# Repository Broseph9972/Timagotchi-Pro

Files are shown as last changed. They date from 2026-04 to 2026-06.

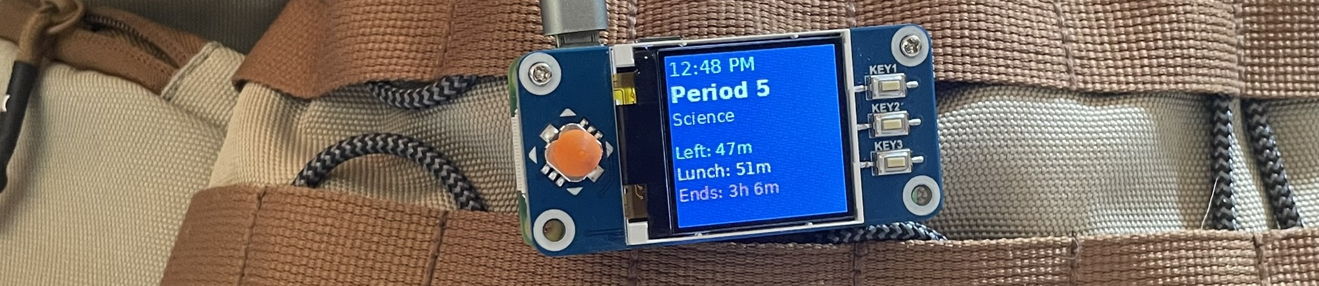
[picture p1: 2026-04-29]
Website/media/timagotchi.jpeg

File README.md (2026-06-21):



# Timagotchi-Pro
The Timagotchi-Pro is a remake of my magnum opus project, the Timagotchi. for info on that checkout [The original Site](https://timagotchi.dev). this is meant to make it accessible for more than just "School schedules" and moving the price from around $50 without crazy deals to ~~$20.~~ ~~$40~~ ~32[^1] I wanted to make it cooler with a joystick, but i kept the budget as small as possible. kinda wish i didnt tbh.
[^1]:(it will be much cheaper if i ever make multiple, but shipping and using premade devboards and screens make it much more annoying The Timagotchi *(time-a-got-chee)* is a low-cost device that helps with adhd time blindness[^2]
[^2]:You're bad at telling how much time has passed
with a progress bar and other features shown to help people with time blindness at a quick glance with many other useful features.
---
<p align="center">
A5 - 1
</p>

<p align="center">
  PCB Schematic
  &nbsp;
  PCB
</p>

<p align="center">
  Casing
</p>

# Assembly

To assemble it it simply Solder the buttons, capacitors, screen connector, xiao, speaker, and JST for battery on, then use the FPC cable from the screen, bend it in a "Z" so it fits in the connectors the right way and also plug in the battery it should automatically charge via usb-c. once the pcb is done, There are 2 parts to the cad, a top and bottom half. Insert the pcb, connect the screen afterputting it in the indent on top. put them together with glue, or don't they should still stay together. you may have to seperate the 2 parts in your slicer, but it should work be easily printable.

# Usage
To use it, simply interact with the menu using the buttons like a d-pad. It's very intuitive, im sure you'll understand.

# Why?
I made it becuase i personally have issues telling how much time is left in class, and was really really bored. turned out to be a really really good idea. ive sold these at school to other kids with adhd and actually made profit??? i made the v2 to reduce price and DRASTICALLY improve quality
---
Some upgrades over the earlier version include

- Price reduction
- Speaker
- Nicer buttons
- kinda better case
- No reliance on raspberry pi
- **A Battery**
- Touchscreen

| Quantity | Name | Price  | Link |
| --- | --- | --- | --- |
| 1 | Conn_01x02_Pin | $0.11  | https://www.digikey.com/en/products/detail/jst-sales-america-inc/B2B-PH-K-S/926611 |
| 1 | Speaker | $4.24  | https://www.digikey.com/en/products/detail/same-sky-formerly-cui-devices/CMS-201438-058S/22602291 |
| 1 | CMS-201438-058S | $1.60  | https://www.digikey.com/en/products/detail/molex/2005280180/13538830\ |
| 1 | XIAO-ESP32-S3-Plus-SMD | $1.86  | Esp32-s3 |
| 1 | MAX98357A | $6.02  | https://www.aliexpress.us/item/3256807631636428.html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 |
| 1 | PCB | $5.22  | JLCPCB |
| 1 | Battery | $0.99  | https://www.aliexpress.us/item/3256802733222186.html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 |
| 1 | Screen | $11.99 | https://www.waveshare.com/product/displays/lcd-oled/lcd-oled-3/1.47inch-touch-lcd.htm |
| | Total | $32.03 | |

This is a project for Hack Club Fallout.

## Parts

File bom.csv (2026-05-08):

Designator | Footprint | Quantity | Designation | Price | Link
J1 | JOYSTICK-PSP1000 | 1 | Conn_01x04 | $0.93 | https://www.adafruit.com/product/444
J2 | JST_PH_B2B-PH-K_1x02_P2.00mm_Vertical | 1 | Conn_01x02_Pin | $0.11 | https://www.digikey.com/en/products/detail/jst-sales-america-inc/B2B-PH-K-S/926611
LS1 | SPKR_CMS-201438-058S | 1 |  | $4.24 | https://www.digikey.com/en/products/detail/same-sky-formerly-cui-devices/CMS-201438-058S/22602291
ScreenConnector1 | CON_2005280180_MOL | 1 | CMS-201438-058S | $1.86 | https://www.digikey.com/en/products/detail/molex/2005280180/13538830\
SW1, SW2, SW3 | SW_SPST_Omron_B3FS-100xP | 3 | SW_Omron_B3FS | $0.99 | https://www.aliexpress.us/item/3256808421842171.html
U1 | XIAO-ESP32-S3-Plus-SMD | 1 | XIAO-ESP32-S3-Plus-SMD | $6.02 | Esp32-s3
U2 | TQFN-16-1EP_3x3mm_P0.5mm_EP1.23x1.23mm | 1 | MAX98357A | $1.51 | https://www.aliexpress.us/item/3256807631636428.html
PCB |  | 1 |  | $5.22 | https://jlcpcb.com/
Battery |  | 1 |  | $0.99 | https://www.aliexpress.us/item/3256802733222186.html?curPageLogUid=4m6JpZeIsJ89
3d Printed parts |  | ? |  | $0.20 | NA
Screen |  | 1 |  | $11.00 | https://www.waveshare.com/product/displays/lcd-oled/lcd-oled-3/1.47inch-touch-lcd.htm
 |  |  | Total | $34.85

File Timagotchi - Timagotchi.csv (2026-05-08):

Designator | Footprint | Quantity | Designation | Price | Link
J1 | JOYSTICK-PSP1000 | 1 | Conn_01x04 | $0.93 | PSP 1000
J2 | JST_PH_B2B-PH-K_1x02_P2.00mm_Vertical | 1 | Conn_01x02_Pin | $0.11 | JST
LS1 | SPKR_CMS-201438-058S | 1 | CMS-201438-058S | $4.24 | Speaker
ScreenConnector1 | CON_2005280180_MOL | 1 | 2005280180 | $1.86 | FFC Connector
SW1, SW2, SW3 | SW_SPST_Omron_B3FS-100xP | 3 | SW_Omron_B3FS | $0.99 | Switches
U1 | XIAO-ESP32-S3-Plus-SMD | 1 | XIAO-ESP32-S3-Plus-SMD | $6.02 | Esp32-s3
U2 | TQFN-16-1EP_3x3mm_P0.5mm_EP1.23x1.23mm | 1 | MAX98357A | $1.51 | Amplifier
PCB |  | 1 |  | $5.22
Battery |  | 1 |  | $1.70
3d Printed parts |  | 3 |  | $0.20
Screen |  | 1 |  | $11.00
 |  |  | Total | $36.16

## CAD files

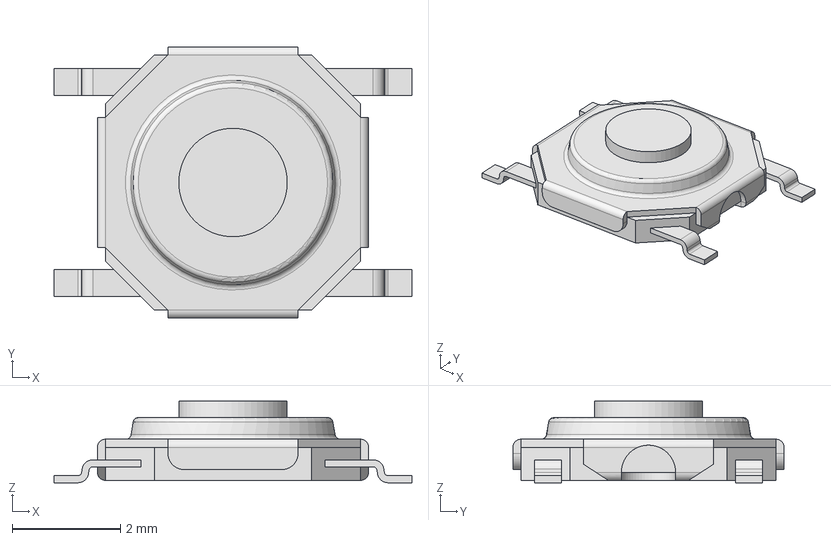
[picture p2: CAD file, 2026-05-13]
Button/TL3342F160QG.step
6.60 x 5.00 x 1.50 mm

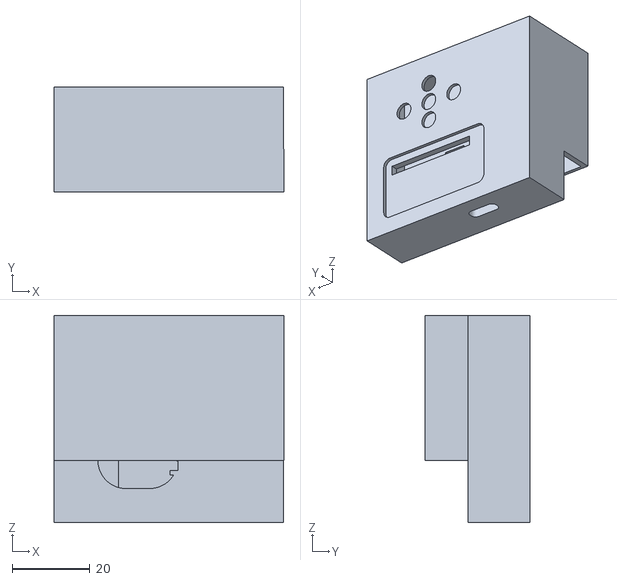
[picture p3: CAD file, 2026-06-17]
Cad/case.stl
59.0 x 27.0 x 53.2

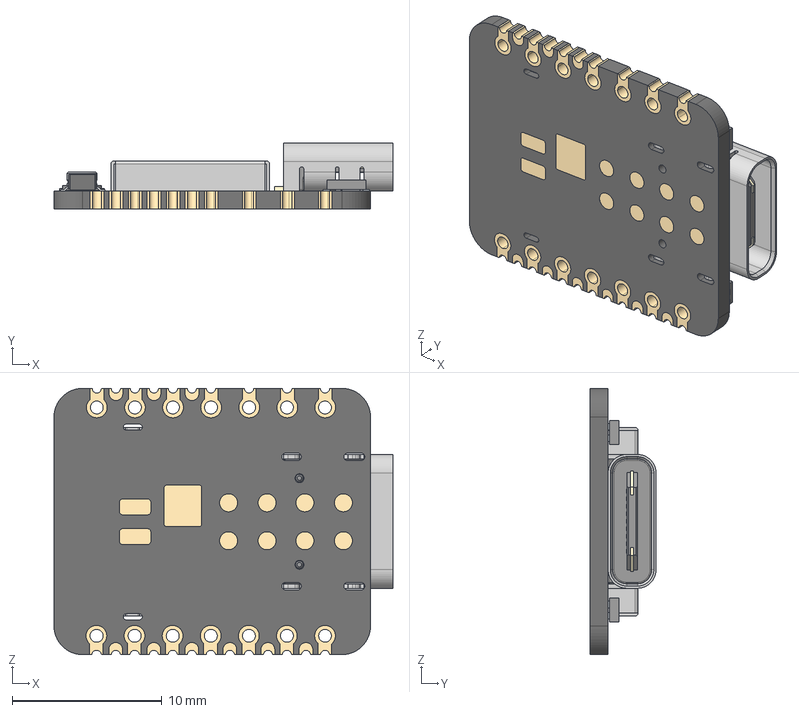
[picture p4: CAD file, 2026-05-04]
PCB/New_XIAO_Series_Footprints/XIAO ESP32S3 PLUS_.step
22.6 x 4.42 x 17.8 mm
DF40C-30DP-0.4V_51_ v1
BOSS-EXTRUDE14_8_
BOSS-EXTRUDE7_4_
BOSS-EXTRUDE7_3_
BOSS-EXTRUDE14_4_
BOSS-EXTRUDE14_2_
BOSS-EXTRUDE14_11_
BOSS-EXTRUDE7_7_
BOSS-EXTRUDE14_9_
BOSS-EXTRUDE14_3_
BOSS-EXTRUDE14_7_
MIRROR2
BOSS-EXTRUDE14_5_
BOSS-EXTRUDE14_12_
BOSS-EXTRUDE7_8_
BOSS-EXTRUDE7_1_
BOSS-EXTRUDE14_10_
BOSS-EXTRUDE7_9_
BOSS-EXTRUDE14_6_
BOSS-EXTRUDE14_1_
BOSS-EXTRUDE7_6_
BOSS-EXTRUDE7_2_
CUT-EXTRUDE5
BOSS-EXTRUDE7_5_
Shield
Pins x 2
U.FL-R-SMT-1_10_ v1

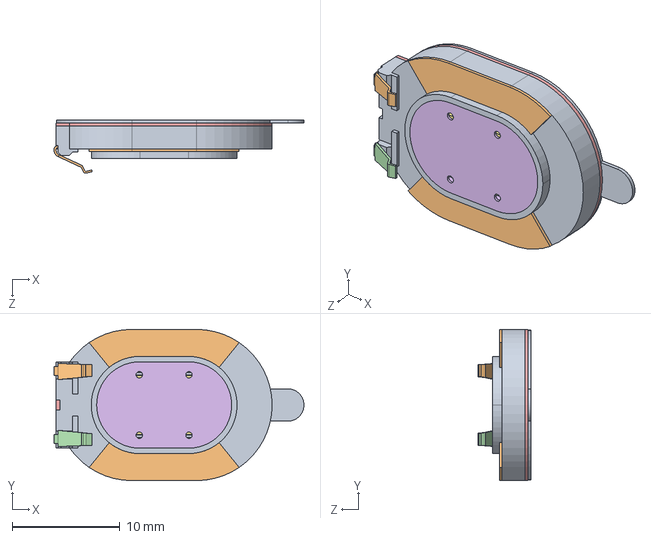
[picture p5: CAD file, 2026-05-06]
PCB/Speaker Footprints/Speaker speaker/CMS-201438-058S.step
23.1 x 14.0 x 4.95 mm

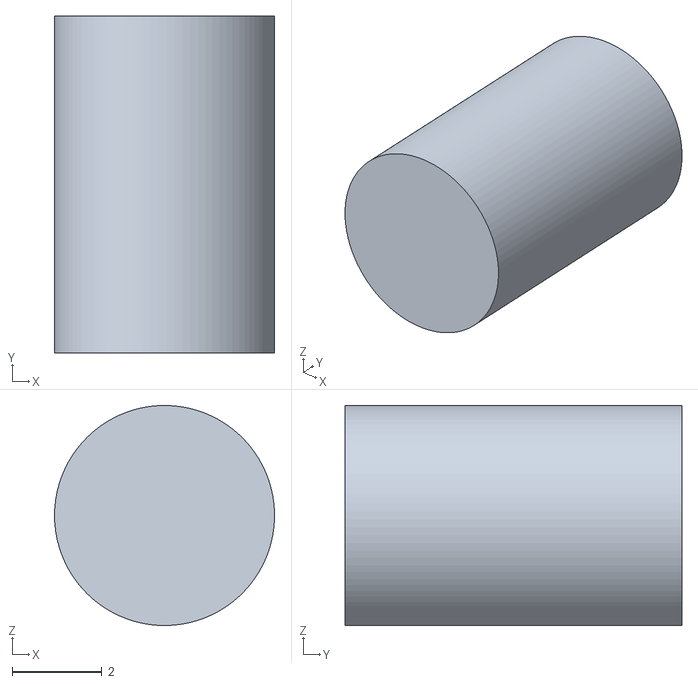
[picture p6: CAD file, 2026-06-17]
Cad/Button thing.stl
4.90 x 7.50 x 4.90

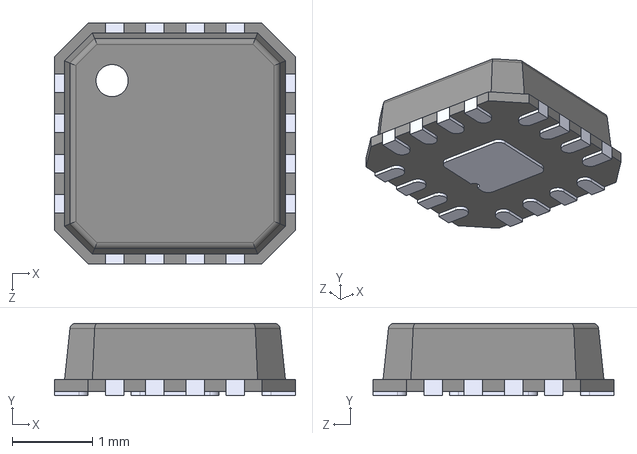
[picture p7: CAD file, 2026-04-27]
PCB/Speaker Footprints/Amp/MAX98357AETE_T.step
3.00 x 0.9 x 3.00 mm

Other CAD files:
Cad/Button thing.f3d
Cad/case.f3d

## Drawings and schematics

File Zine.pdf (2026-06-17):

File | Edit | View | Help

# Timagotchi

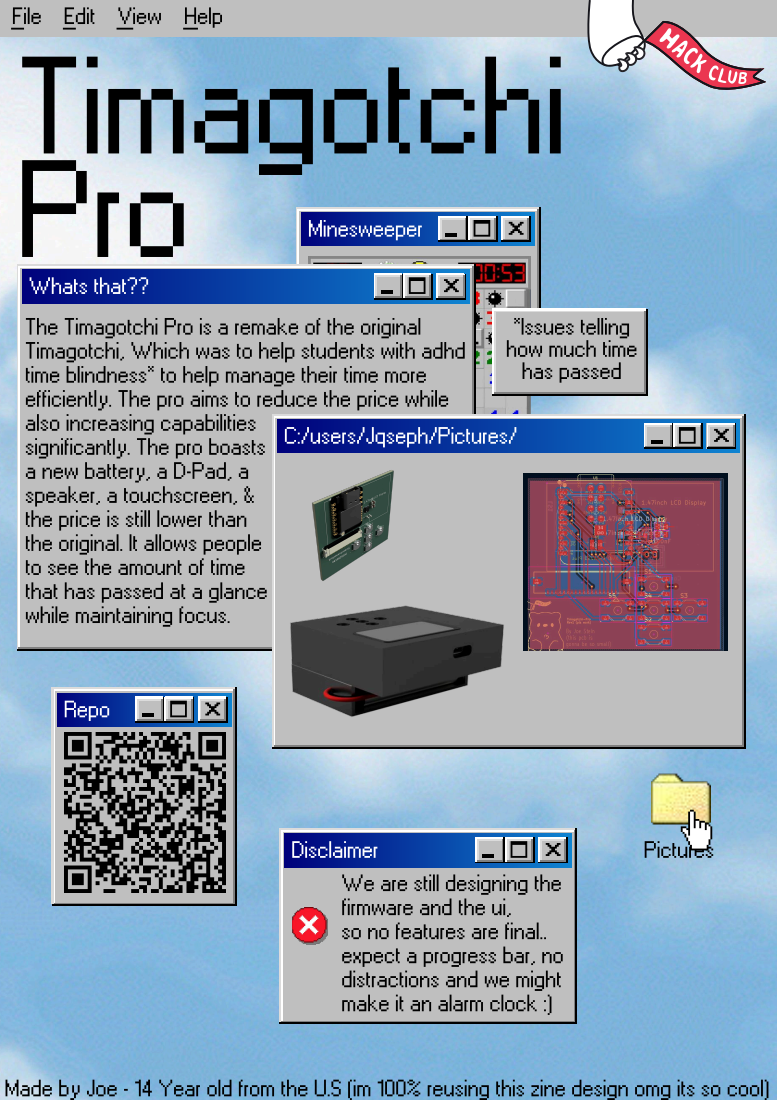
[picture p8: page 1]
Pro; Minesweeper; Whats; that??; speaker, a touchscreen, &; *Issues telling; has passed; Repo; Disclaimer; Pictures

The Timagotchi Pro is a remake of the original

Timagotchi, Which was to help students with adhd

how much time

time blindness* to help manage their time more

efficiently. The pro aims to reduce the price while

also increasing capabilities

C:/users/Jqseph/Pictures/

significantly. The pro boasts

a new battery, a D-Pad, a

the price is still lower than

the original. It allows people

to see the amount of time

that has passed at a glance

while maintaining focus.

We are still designing the

firmware and the ui,

so no features are final..

expect a progress bar, no

distractions and we might
make it an alarm clock :)

Made by Joe - 14 Year old from the U.S (im 100% reusing this zine design omg its so cool)

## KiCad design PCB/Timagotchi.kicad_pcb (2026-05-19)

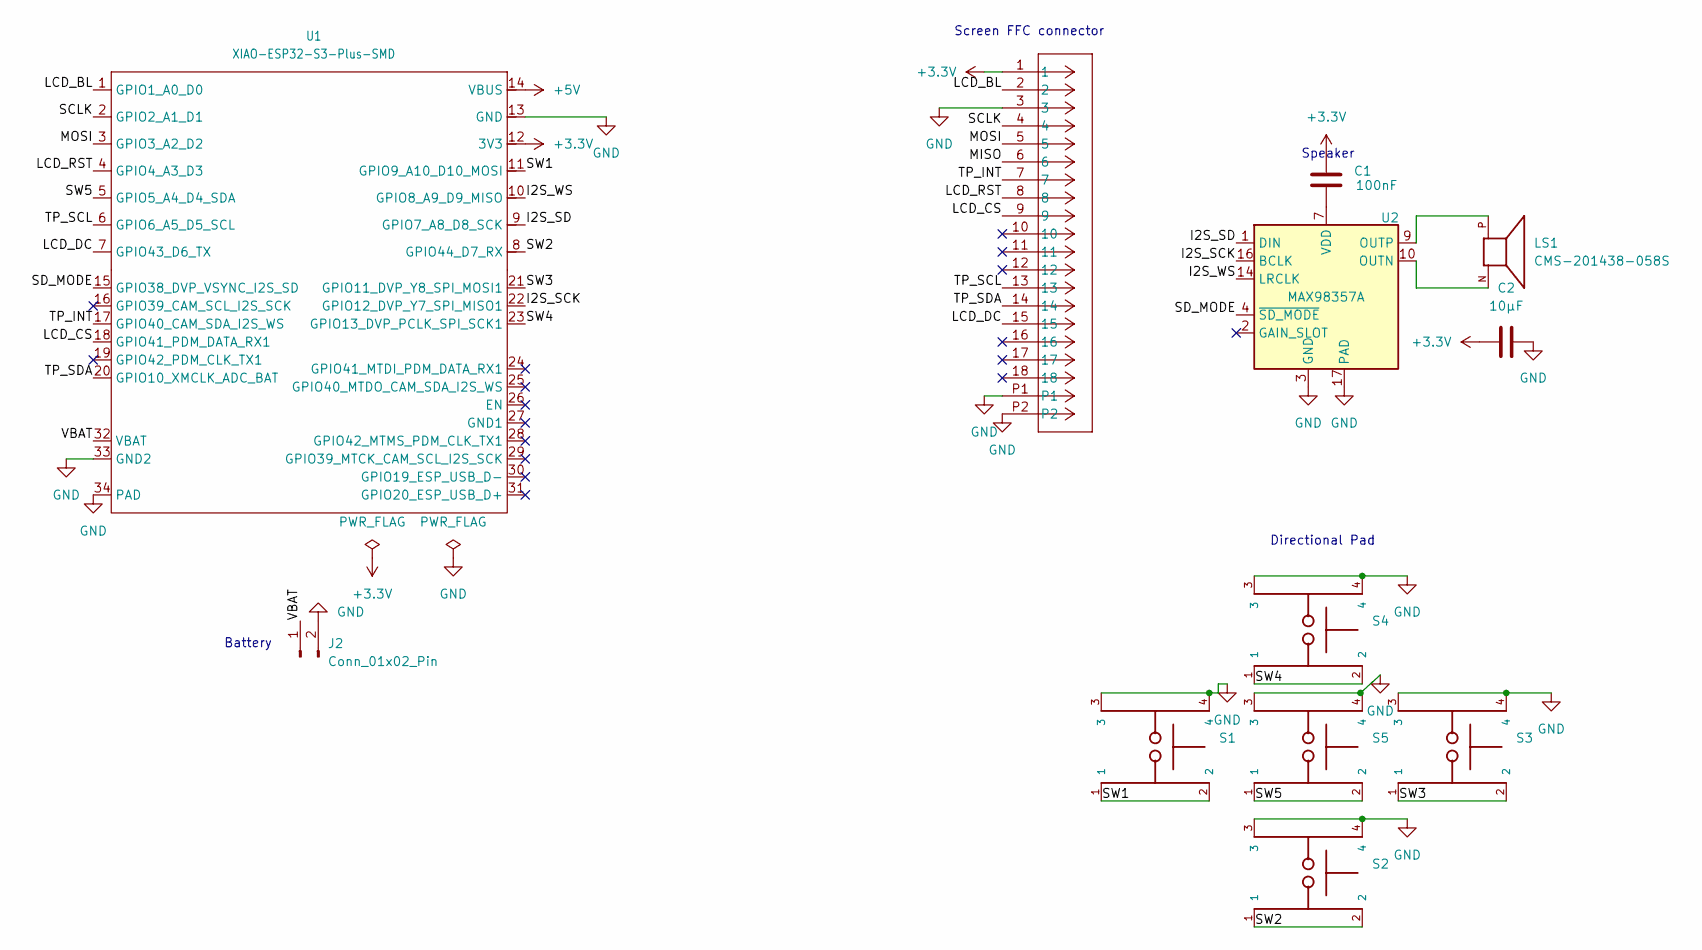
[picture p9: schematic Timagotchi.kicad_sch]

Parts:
C1: 100nF; C_0805_2012Metric_Pad1.18x1.45mm_HandSolder
C2: 10µF; C_0805_2012Metric_Pad1.18x1.45mm_HandSolder
J2: Conn_01x02_Pin; JST_PH_B2B-PH-K_1x02_P2.00mm_Vertical
LS1: CMS-201438-058S; SPKR_CMS-201438-058S; PARTREV 1.03
S1, S2, S3, S4, S5: TL3342F160QG; SW_TL3342F160QG
ScreenConnector1: 2005280180; CON_2005280180_MOL
U1: XIAO-ESP32-S3-Plus-SMD
U2: MAX98357A; TQFN-16-1EP_3x3mm_P0.5mm_EP1.23x1.23mm

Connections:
+3.3V: C1.1, C2.1, ScreenConnector1.1, U1.12 (3V3)
+5V: U1.14 (VBUS)
/I2S_SCK: U1.22 (GPIO12_DVP_Y7_SPI_MISO1), U2.16 (BCLK)
/I2S_SD: U1.9 (GPIO7_A8_D8_SCK), U2.1 (DIN)
/I2S_WS: U1.10 (GPIO8_A9_D9_MISO), U2.14 (LRCLK)
/LCD_BL: ScreenConnector1.2, U1.1 (GPIO1_A0_D0)
/LCD_CS: ScreenConnector1.9, U1.18 (GPIO41_PDM_DATA_RX1)
/LCD_DC: ScreenConnector1.15, U1.7 (GPIO43_D6_TX)
/LCD_RST: ScreenConnector1.8, U1.4 (GPIO4_A3_D3)
/MISO: ScreenConnector1.6
/MOSI: ScreenConnector1.5, U1.3 (GPIO3_A2_D2)
/SCLK: ScreenConnector1.4, U1.2 (GPIO2_A1_D1)
/SD_MODE: U1.15 (GPIO38_DVP_VSYNC_I2S_SD), U2.4 (~SD_MODE)
/SW1: S1.1, S1.2, U1.11 (GPIO9_A10_D10_MOSI)
/SW2: S2.1, S2.2, U1.8 (GPIO44_D7_RX)
/SW3: S3.1, S3.2, U1.21 (GPIO11_DVP_Y8_SPI_MOSI1)
/SW4: S4.1, S4.2, U1.23 (GPIO13_DVP_PCLK_SPI_SCK1)
/SW5: S5.1, S5.2, U1.5 (GPIO5_A4_D4_SDA)
/TP_INT: ScreenConnector1.7, U1.17 (GPIO40_CAM_SDA_I2S_WS)
/TP_SCL: ScreenConnector1.13, U1.6 (GPIO6_A5_D5_SCL)
/TP_SDA: ScreenConnector1.14, U1.20 (GPIO10_XMCLK_ADC_BAT)
/VBAT: J2.1, U1.32 (VBAT)
GND: C2.2, J2.2, S1.3, S1.4, S2.3, S2.4, S3.3, S3.4, S4.3, S4.4, S5.3, S5.4, ScreenConnector1.3, ScreenConnector1.P1, ScreenConnector1.P2, U1.13 (GND), U1.33 (GND2), U1.34 (PAD), U2.3 (GND), U2.11 (GND), U2.15 (GND), U2.17 (PAD)
unnamed: C1.2, U2.7 (VDD), U2.8 (VDD)
unnamed: LS1.N, U2.10 (OUTN)
unnamed: LS1.P, U2.9 (OUTP)

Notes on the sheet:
Directional Pad
Battery
Speaker
Screen FFC connector

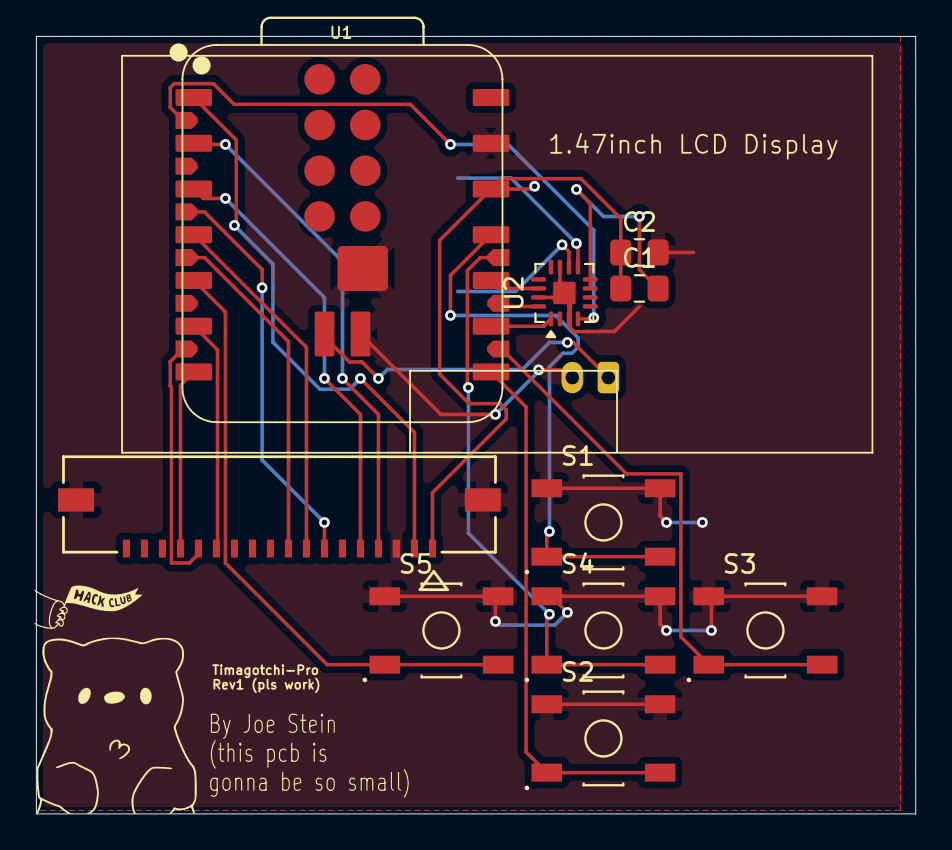
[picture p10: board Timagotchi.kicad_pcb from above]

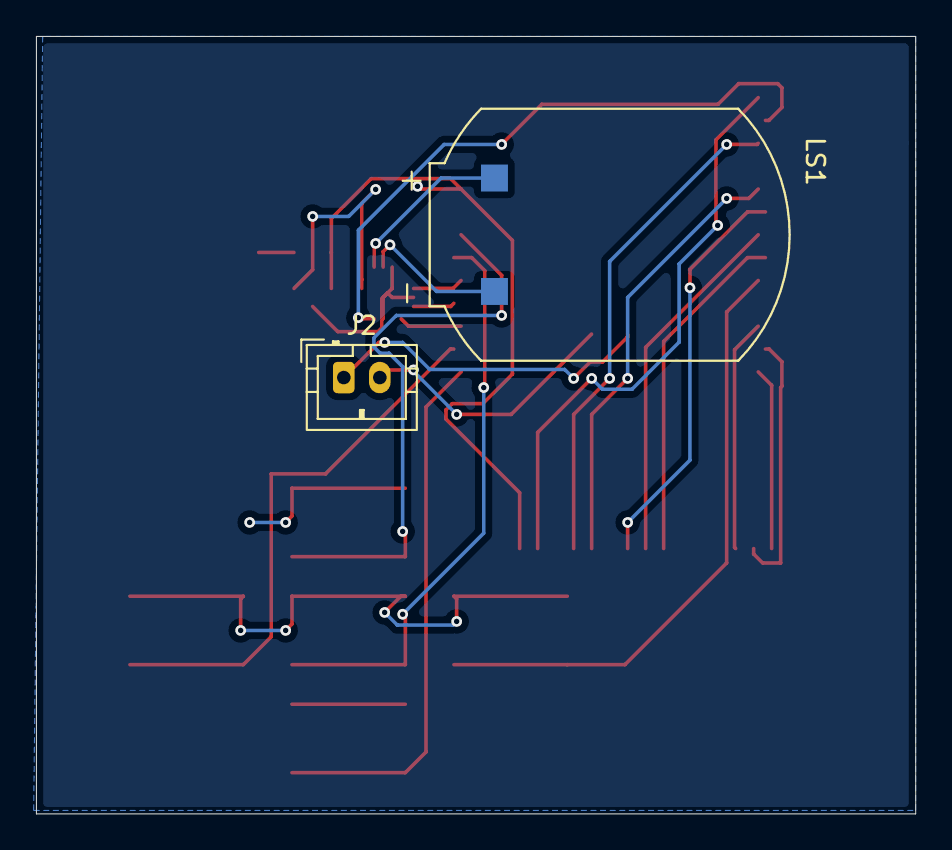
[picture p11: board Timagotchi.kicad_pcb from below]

Board: 2 copper layers, 48.8 x 43.2 mm, 13 parts (2 on the bottom side), 24 nets.

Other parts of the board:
1.47inch LCD Display: 1.47inch LCD Display

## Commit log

2026-04-22 Added kicad gitignore from reddit and empty kicad project.
2026-04-23 some work on pcb
    [Timagotchi.kicad_sch]
2026-04-23 got battery pins and screen setup :)
    [Timagotchi.kicad_sch]
2026-04-26 Added switches footprints and libraries
    [B3F-4055.step]
2026-04-27 Done for today
    [MAX98357AETE_T.step]
2026-04-29 a bunch of stuff
    [Timagotchi.kicad_pcb, Timagotchi.kicad_sch]
2026-04-29 made pcb folder
    [B3F-4055.step, COM-09032.step, MAX98357AETE_T.step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]
2026-04-30 pcb joystick
    [COM-09032.step, Timagotchi.kicad_pcb, Timagotchi.kicad_sch]
2026-05-02 optimizations and other stuff.
    [Timagotchi.kicad_pcb, Timagotchi.kicad_sch]
2026-05-03 found the backup idk 🗿
2026-05-04 added a testfile from wiringpi for python
2026-05-04 Pcb changes, mostly files and 3d models.
    [COM-09032.step, FH12-18S-0.5SH.stp, Timagotchi.kicad_pcb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]
2026-05-05 puh cuh buh 2
    [Timagotchi.kicad_pcb, Timagotchi.kicad_sch]
2026-05-06 wiring and new speaker
    added CMS-201438-058S
    speaker and new gpio wiring
    [CMS-201438-058S.step, MAX98357AETE_T.step, Timagotchi.kicad_sch]
2026-05-06 deleted wiringpi
2026-05-07 PCB wiringgg
    [Timagotchi.kicad_pcb]
2026-05-07 moved the battery connector to the back
    [Timagotchi.kicad_pcb]
2026-05-08 pcb stuff
    [Timagotchi.kicad_pcb]
2026-05-08 Added The BOM
    [Timagotchi - Timagotchi.csv]
2026-05-08 Rename Timagotchi - Timagotchi.csv to BOM
2026-05-08 links to bom
    [bom.csv]
2026-05-11 new pcb bc the screen wont fit :( but its fixed.
    [Timagotchi.kicad_pcb]
2026-05-12 some change i dunno what
    [Timagotchi.kicad_pcb]
2026-05-13 PCB UHH delete later maybe
    [B3F-4055.step, TL3342F160QG.step, Timagotchi.kicad_pcb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]
2026-05-17 lots of stuff
    [Timagotchi.kicad_pcb, Timagotchi.kicad_sch]
2026-05-17 wrl file for blender later and a new step file
    [Timagotchi.kicad_pcb]
2026-05-17 Power flags and a nc symbol
    [Timagotchi.kicad_pcb, Timagotchi.kicad_sch]
2026-05-19 Some stuff
    [Timagotchi.kicad_pcb]
2026-06-04 add fusion 360 case files
2026-06-04 cad folder
2026-06-17 cad cad cad cad cad cad
    [Button thing.f3d, Button thing.stl, case.f3d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]
